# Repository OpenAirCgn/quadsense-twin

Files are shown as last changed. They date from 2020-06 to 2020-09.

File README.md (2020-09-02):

# quadsense-twin

This repository contains schematics and board files for an OpenAir
module intended to evaluate the viability of an alternative circuitry to
Alphasense provided ISB (individual support board) for gas sensors.

The board design is based on the original quadsense, with two ISB
mounted sensors replaced by sensors mounted directly on the board. The
support circuitry provided by the ISB boards is integrated directly on
the board.

# Circuitry

Each sensor has four electrodes. The circuit to the left of the sensor
maintains a constant voltage at the counter and reference electrodes.
The circuitry to the right of the electrodes amplifies and filters the
current flowing from the working and auxiliary electrodes.

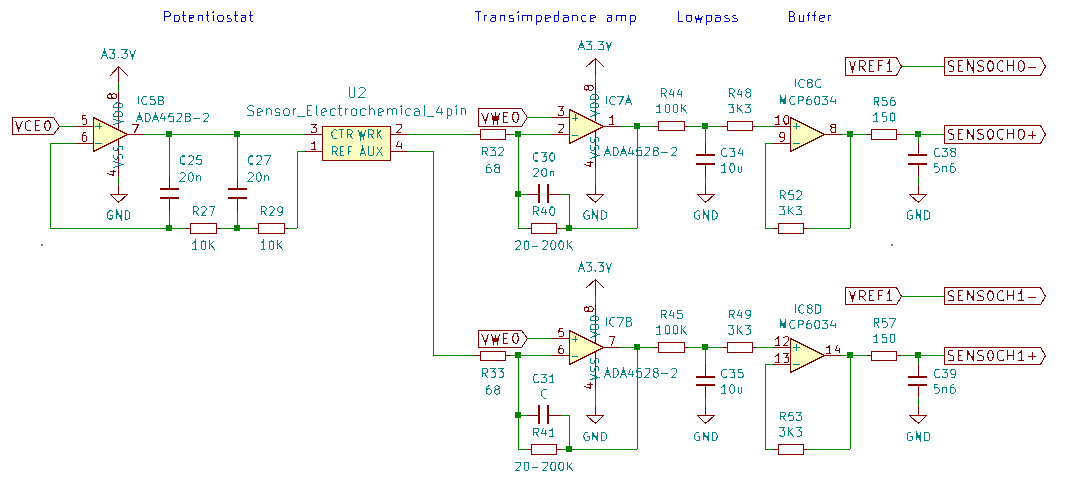
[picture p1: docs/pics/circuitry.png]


The concentration being measured is proportional to the difference of
the working electrode exposed to the gas and the unexposed auxiliary
electrode.

The voltage maintained at the referenced and counter electrodes may be offset
by a bias voltage. 

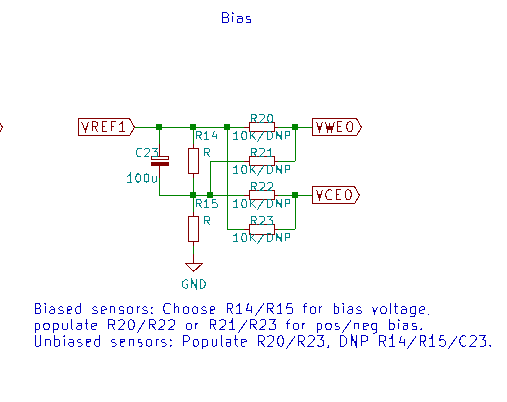
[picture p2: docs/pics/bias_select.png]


Whether a positive or negative bias voltage is applied voltage
determined by jumper configuration (U1: R16/R17 & R18/R19, U2: R20/R21 &
R22/R23). The value of the bias is determined by a voltage divider (U1:
R12/R13, U2:R14/R15). 

The photograph below highlights an unbiased (U2, top rectangle) and 200mV biased
configuration (U1, bottom rectangle, R12=15k R13=12k). 

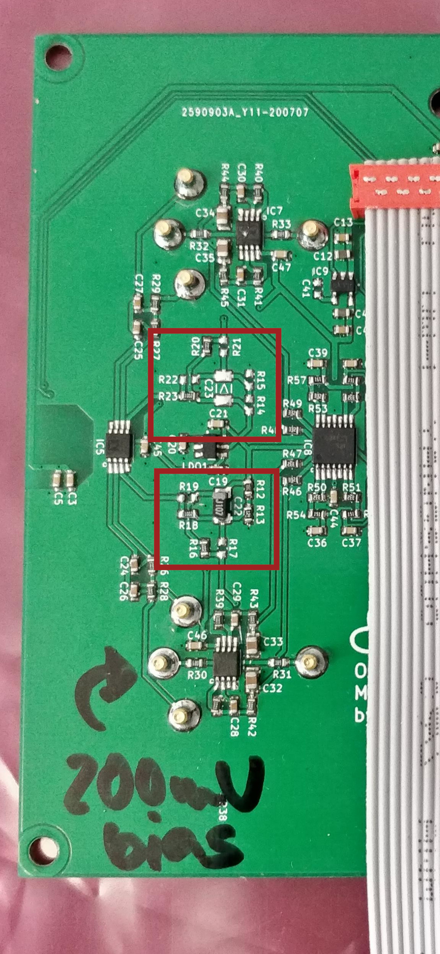
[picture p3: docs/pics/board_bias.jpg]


# Test boards

| MAC | Sensor U1 | Sensor U2 | ISB 1 | ISB 2 |
|-|-|-|-|-|
| 30:AE:A4:0A:AA:98 | [C0-B4](http://www.alphasense.com/WEB1213/wp-content/uploads/2019/09/CO-B4.pdf) | [OX-B431](http://www.alphasense.com/WEB1213/wp-content/uploads/2019/09/OX-B431.pdf) | CO-B4 | OX-B431 |
| 30:AE:A4:0A:A9:D8 | [NO-B4](http://www.alphasense.com/WEB1213/wp-content/uploads/2019/09/NO-B4.pdf) (biased) | [NO2-B43F](http://www.alphasense.com/WEB1213/wp-content/uploads/2019/09/NO2-B43F.pdf) | NO-B4 | NO2-B43F |

# Sensor Configuration

The following picture and table describe the sensor configuration:

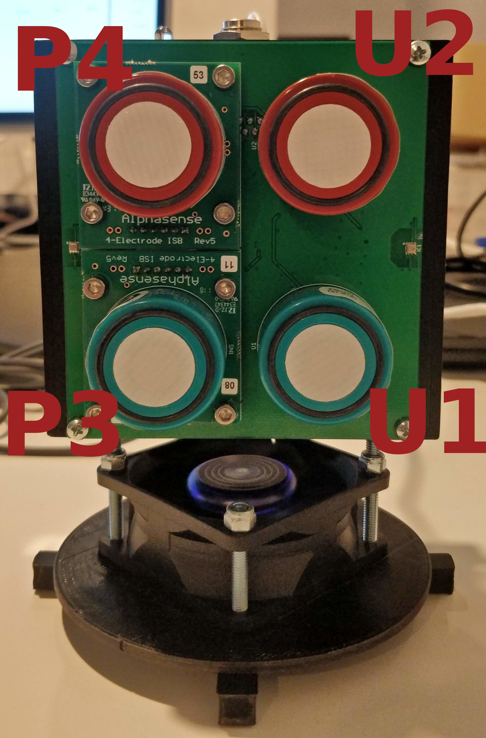
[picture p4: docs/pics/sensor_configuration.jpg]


| Name Schematic | ADC Channel | Tag Firehose | Name Firehose | Sensor AA:98 | Sensor A9:D8 |
| -- | - | - | - | - | - |
| U1 | 2 | 0x03 | OA_Alpha_3 | CO-B4 working electrode | NO-B4 working |
| U1 | 3 | 0x04 | OA_Alpha_4 | CO-B4 auxiliary electrode | NO-B4 AUX |
| U2 | 0 | 0x01 | OA_Alpha_1 | OX-B431 working | NO2-B43F working |
| U2 | 1 | 0x02 | OA_Alpha_2 | OX-B431 AUX | NO2-B43F AUX |
| P3 | 4 | 0x05 | OA_Alpha_5 | CO-B4 (ISB) working | NO-B4 (ISB) working |
| P3 | 5 | 0x06 | OA_Alpha_6 | CO-B4 (ISB) AUX | NO-B4 (ISB) AUX |
| P4 | 6 | 0x07 | OA_Alpha_7 | OX-B431 (ISB) working | NO2-B43F (ISB) working |
| P4 | 7 | 0x08 | OA_Alpha_8 | OX-B431 (ISB) AUX | NO2-B43F (ISB) AUX |

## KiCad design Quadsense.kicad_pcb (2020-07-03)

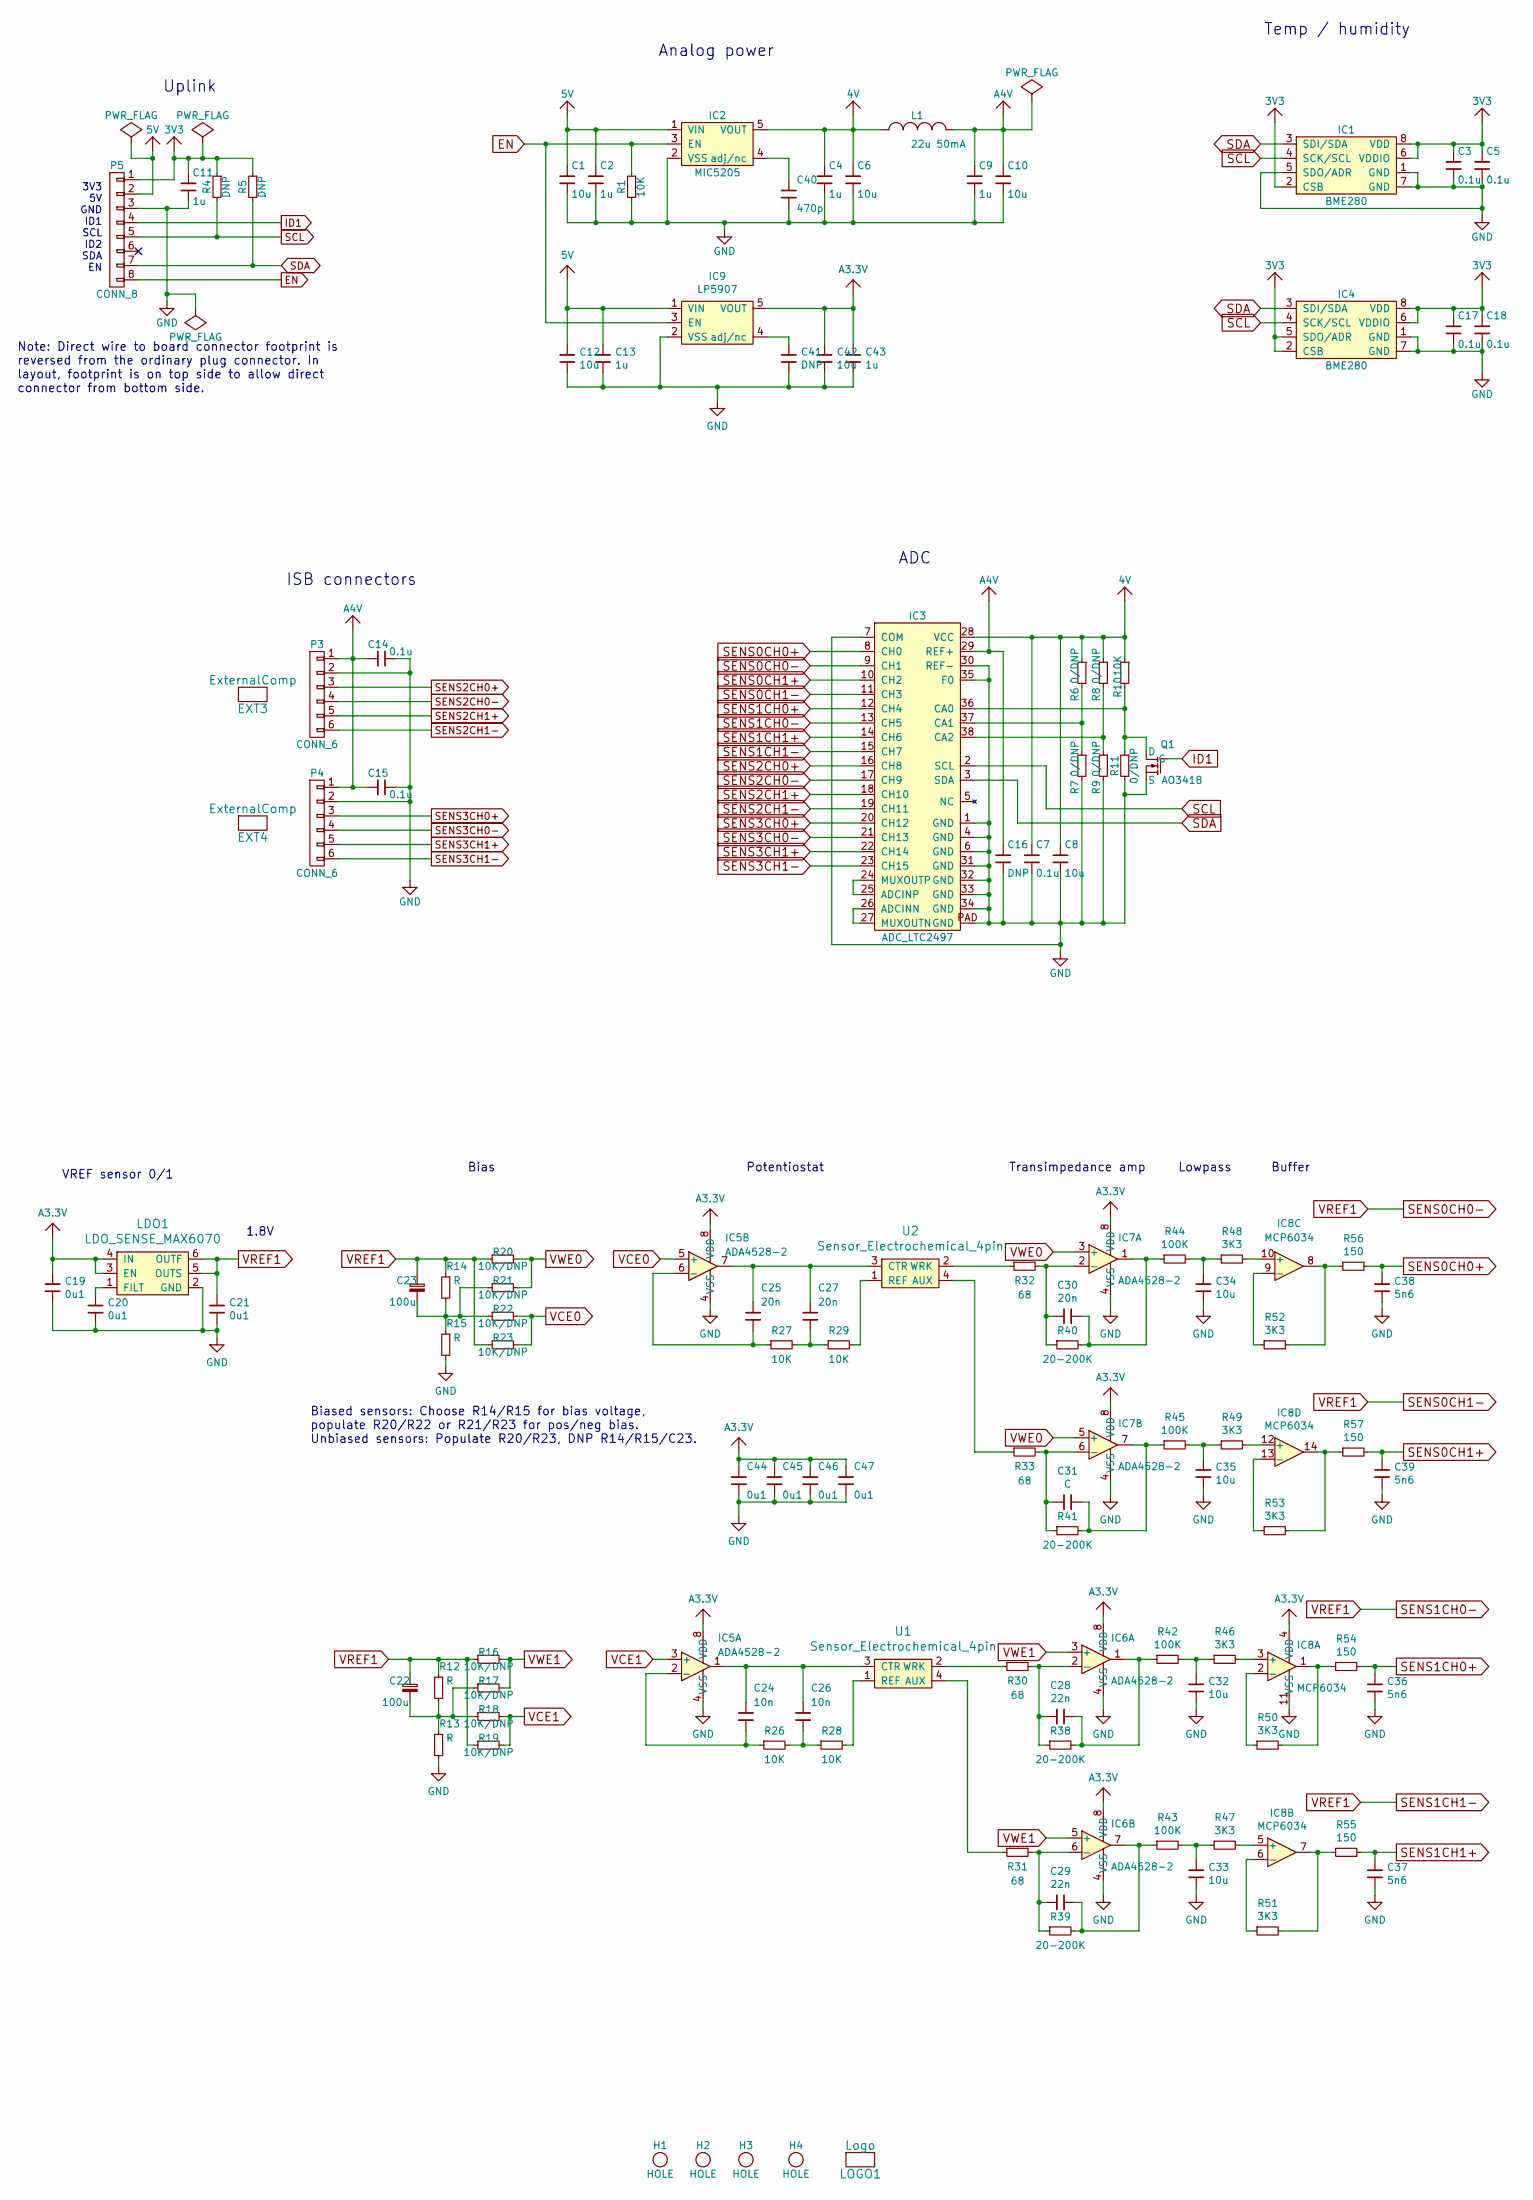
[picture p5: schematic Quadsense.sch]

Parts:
C1, C6, C8, C10, C12, C42: 10u; 0603
C2, C4, C9, C11, C13, C43: 1u; 0603
C3, C5, C7, C14, C15, C17, C18: 0.1u; 0603
C16, C41: DNP; 0603
C19, C20, C21, C44, C45, C46, C47: 0u1; 0603
C22, C23: 100u; 1206-POLAR
C24, C26: 10n; 0603
C25, C27, C30: 20n; 0603
C28, C29: 22n; 0603
C31: C; 0603
C32, C33, C34, C35: 10u; 0805
C36, C37, C38, C39: 5n6; 0603
C40: 470p; 0603
EXT3, EXT4: ExternalComp; ALPHASENSE-ISB
H1, H2, H3, H4: HOLE; HOLE-3.2
IC1, IC4: BME280
IC2: MIC5205; SOT23-5
IC3: ADC_LTC2497; QFN-38-12-7-0.5-EP
IC5, IC6, IC7: ADA4528-2; MSOP-8
IC8: MCP6034; TSSOP-14-0.65-4.4
IC9: LP5907; SOT23-5
L1: 22u 50mA; 0805
LDO1: LDO_SENSE_MAX6070; SOT23-6
LOGO1: Logo
P3, P4: CONN_6; HEADER-1x06-1.27-ZZ-POL
P5: CONN_8; HEADER-1x08-1.27-ZZ-POL
Q1: AO3418; SOT23-3
R1, R10, R26, R27, R28, R29: 10K; 0603
R4, R5: DNP; 0603
R6, R7, R8, R9, R11: 0/DNP; 0603
R12, R13, R14, R15: R; 0603
R16, R17, R18, R19, R20, R21, R22, R23: 10K/DNP; 0603
R30, R31, R32, R33: 68; 0603
R38, R39, R40, R41: 20-200K; 0603
R42, R43, R44, R45: 100K; 0603
R46, R47, R48, R49, R50, R51, R52, R53: 3K3; 0603
R54, R55, R56, R57: 150; 0603
U1, U2: Sensor_Electrochemical_4pin; ALPHASENSE_B4

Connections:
4V: C4.1, C6.1, C7.1, C8.1, IC2.5 (VOUT), IC3.28 (VCC), L1.1, R6.1, R8.1, R10.1
A3V3: C19.1, C42.1, C43.1, C44.1, C45.1, C46.1, C47.1, IC5.8 (VDD), IC6.8 (VDD), IC7.8 (VDD), IC8.4 (VDD), IC9.5 (VOUT), LDO1.3 (EN), LDO1.4 (IN)
EN: IC2.3 (EN), IC9.3 (EN), P5.8, R1.1
ID1: P5.4, Q1.1 (G)
unnamed: C20.1, LDO1.1 (FILT)
unnamed: C22.K (-), R12.2, R13.1, R17.1, R18.1
unnamed: C23.K (-), R14.2, R15.1, R21.1, R22.1
unnamed: C24.1, C26.1, IC5.1, U1.3 (CTR)
unnamed: C24.2, IC5.2 (-), R26.1
unnamed: C25.1, C27.1, IC5.7, U2.3 (CTR)
unnamed: C25.2, IC5.6 (-), R27.1
unnamed: C26.2, R26.2, R28.1
unnamed: C27.2, R27.2, R29.1
unnamed: C28.1, IC6.1, R38.2, R42.1
unnamed: C28.2, IC6.2 (-), R30.2, R38.1
unnamed: C29.1, IC6.7, R39.2, R43.1
unnamed: C29.2, IC6.6 (-), R31.2, R39.1
unnamed: C30.1, IC7.1, R40.2, R44.1
unnamed: C30.2, IC7.2 (-), R32.2, R40.1
unnamed: C31.1, IC7.7, R41.2, R45.1
unnamed: C31.2, IC7.6 (-), R33.2, R41.1
unnamed: C32.1, R42.2, R46.1
unnamed: C33.1, R43.2, R47.1
unnamed: C34.1, R44.2, R48.1
unnamed: C35.1, R45.2, R49.1
unnamed: C40.1, IC2.4 (adj/nc)
unnamed: C41.1, IC9.4 (adj/nc)
unnamed: IC3.24 (MUXOUTP), IC3.25 (ADCINP)
unnamed: IC3.26 (ADCINN), IC3.27 (MUXOUTN)
unnamed: IC3.36 (CA0), Q1.3 (D), R10.2, R11.1
unnamed: IC3.37 (CA1), R6.2, R7.1
unnamed: IC3.38 (CA2), R8.2, R9.1
unnamed: IC8.1, R50.2, R54.1
unnamed: IC8.2 (-), R50.1
unnamed: IC8.3 (+), R46.2
unnamed: IC8.5 (+), R47.2
unnamed: IC8.6 (-), R51.1
unnamed: IC8.7, R51.2, R55.1
unnamed: IC8.8, R52.2, R56.1
unnamed: IC8.9 (-), R52.1
unnamed: IC8.10 (+), R48.2
unnamed: IC8.12 (+), R49.2
unnamed: IC8.13 (-), R53.1
unnamed: IC8.14, R53.2, R57.1
unnamed: R28.2, U1.1 (REF)
unnamed: R29.2, U2.1 (REF)
unnamed: R30.1, U1.2 (WRK)
unnamed: R31.1, U1.4 (AUX)
unnamed: R32.1, U2.2 (WRK)
unnamed: R33.1, U2.4 (AUX)
SCL: IC1.4 (SCK/SCL), IC3.2 (SCL), IC4.4 (SCK/SCL), P5.5, R4.2
SDA: IC1.3 (SDI/SDA), IC3.3 (SDA), IC4.3 (SDI/SDA), P5.7, R5.2
SENS0CH0+: C38.1, IC3.8 (CH0), R56.2
SENS0CH0-: C21.1, C22.A (+), C23.A (+), IC3.9 (CH1), IC3.11 (CH3), IC3.13 (CH5), IC3.15 (CH7), LDO1.5 (OUTS), LDO1.6 (OUTF), R12.1, R14.1, R16.1, R19.1, R20.1, R23.1
SENS0CH1+: C39.1, IC3.10 (CH2), R57.2
SENS1CH0+: C36.1, IC3.12 (CH4), R54.2
SENS1CH1+: C37.1, IC3.14 (CH6), R55.2
SENS2CH0+: IC3.16 (CH8), P3.3
SENS2CH0-: IC3.17 (CH9), P3.4
SENS2CH1+: IC3.18 (CH10), P3.5
SENS2CH1-: IC3.19 (CH11), P3.6
SENS3CH0+: IC3.20 (CH12), P4.3
SENS3CH0-: IC3.21 (CH13), P4.4
SENS3CH1+: IC3.22 (CH14), P4.5
SENS3CH1-: IC3.23 (CH15), P4.6
VCE0: IC5.5 (+), R22.2, R23.2
VCE1: IC5.3 (+), R18.2, R19.2
VWE0: IC7.3 (+), IC7.5 (+), R20.2, R21.2
VWE1: IC6.3 (+), IC6.5 (+), R16.2, R17.2

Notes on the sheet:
3V3 5V GND ID1 SCL ID2 SDA EN
Uplink
ISB connectors
Analog power
Temp / humidity
ADC
Note: Direct wire to board connector footprint is reversed from the ordinary plug connector. In layout, footprint is on top side to allow direct connector from bottom side.
VREF sensor 0/1
Bias
Potentiostat
Transimpedance amp
Buffer
Lowpass
Biased sensors: Choose R14/R15 for bias voltage, populate R20/R22 or R21/R23 for pos/neg bias. Unbiased sensors: Populate R20/R23, DNP R14/R15/C23.
1.8V

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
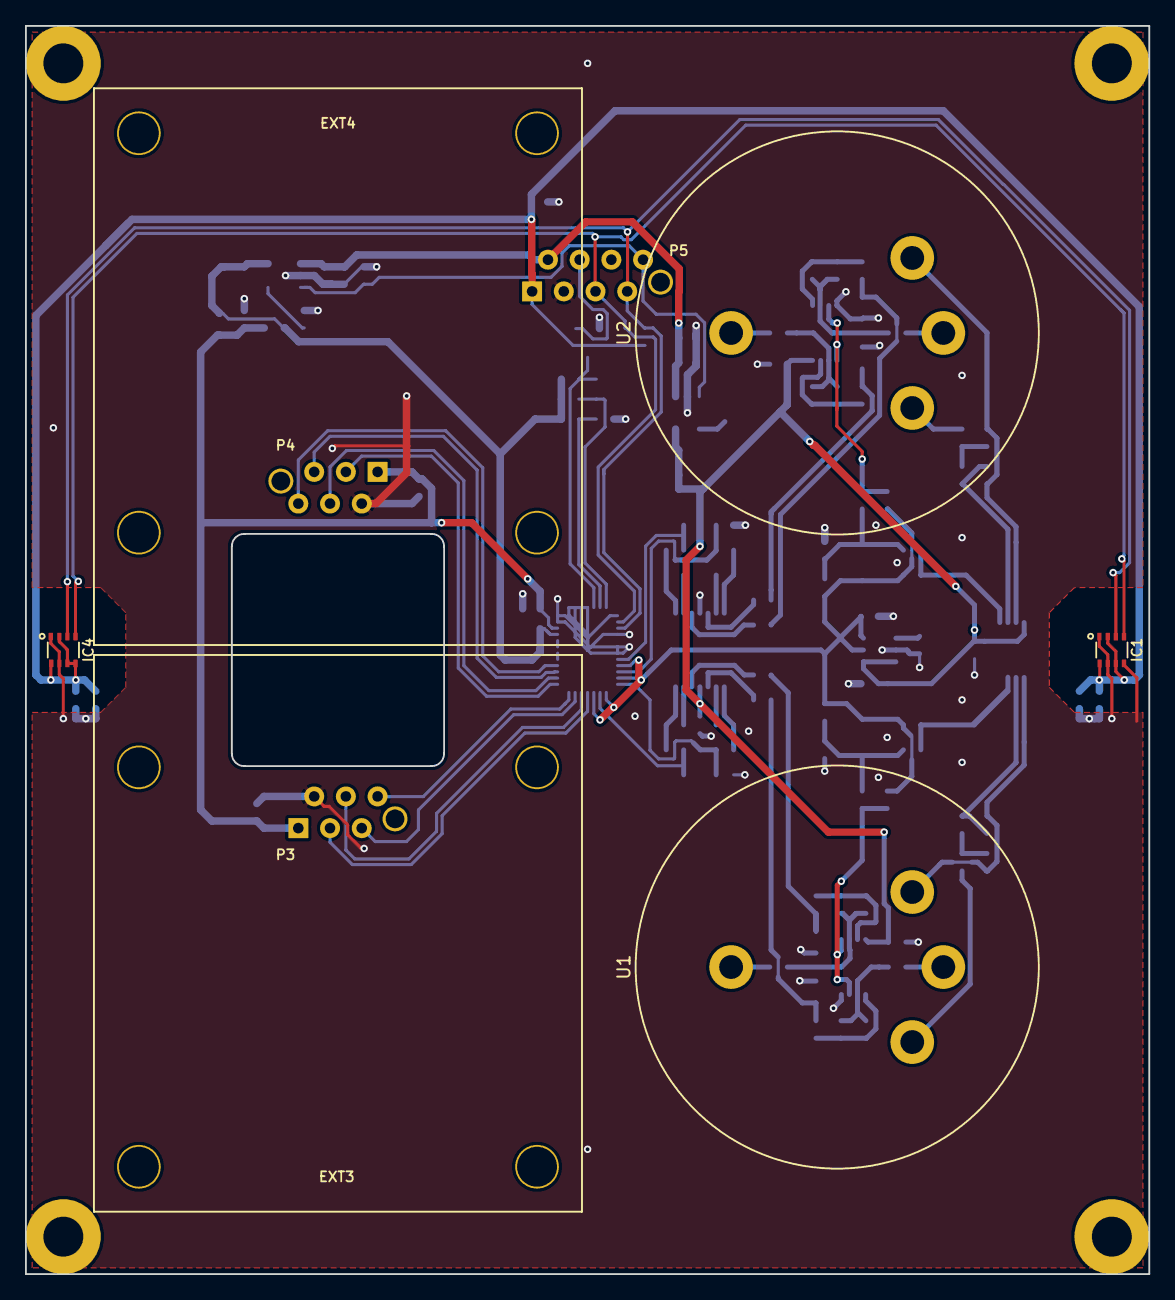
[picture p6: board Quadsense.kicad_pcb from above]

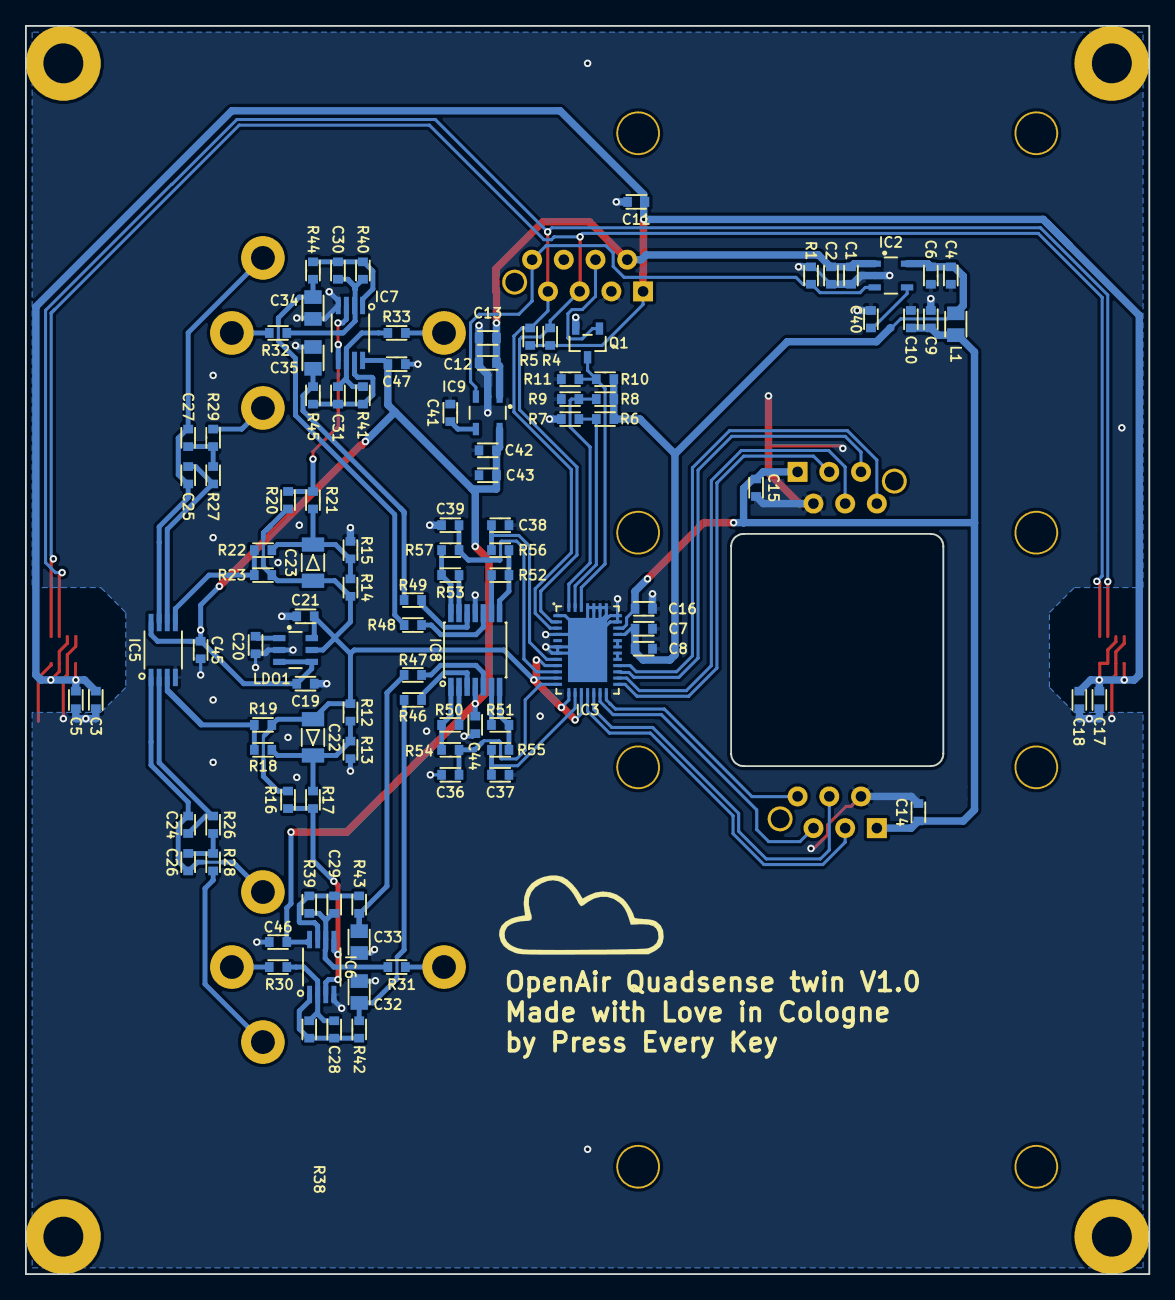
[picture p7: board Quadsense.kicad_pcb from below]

Board: 2 copper layers, 90.0 x 100.0 mm, 120 parts (107 on the bottom side), 73 nets.

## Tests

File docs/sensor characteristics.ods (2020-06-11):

CO-B4 sens 420 - 650 nA/ppm max 1000 ppm zero -250 - 30 nA load 33-100Ω bias 0mv (WE above CE)
NO2-B43F sens -200 - -650 nA/ppm max 20 ppm zero -80 - 80 nA load 33-100Ω bias 0mv (WE above CE)
NO-B4 sens 500 - 850 nA/ppm max 20 ppm zero -80 - 80 nA load 33-100Ω bias 0mv (WE above CE)
OX-B431 sens -200 - -650 nA/ppm max 20 ppm zero -80 - 80 nA load 33-100Ω bias 0mv (WE above CE)
Sensor | sens min | sens max | max load | zero min | zero max | load min | load max | bias | range max | max curr | Vdiff at K | Vout at K | Vout at K
 | nA/ppm | nA/ppm | ppm | nA | nA | Ω | Ω | mV (WE+) | ppm | nA | 22 | 100 | 470
CO-B4 | 420 | 650 | 1000 | -250 | 30 | 33 | 100 | 0 | 100 | 65030 | 1,43066 | 6,503 | 30,5641
NO2-B43F | -200 | -650 | 20 | -80 | 80 | 33 | 100 | 0 | 2 | -1380 | -0,03036 | -0,138 | -0,6486
NO-B4 | 500 | 850 | 20 | 30 | 200 | 33 | 100 | 200 | 1 | 1050 | 0,0231 | 0,105 | 0,4935
OX-B431 | -225 | -700 | 20 | -80 | 80 | 33 | 100 | 0 | 1 | -780 | -0,01716 | -0,078 | -0,3666

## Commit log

2020-06-11 Schematics cleanup
    [Quadsense.sch]
2020-07-03 Changed version on silkscreen
    [Quadsense.kicad_pcb]
2020-07-07 gerber files as sent to production 2020-07-06
    [Quadsense-B_Cu.gbr, Quadsense-B_Mask.gbr, Quadsense-B_SilkS.gbr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]
